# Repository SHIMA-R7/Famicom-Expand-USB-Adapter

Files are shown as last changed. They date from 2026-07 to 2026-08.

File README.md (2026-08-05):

# Famicom Expand USB Adapter

ファミリーベーシックキーボードとファミコン光線銃(ザッパー)を、USB HIDキーボード/マウスとしてPCで使えるようにするアダプター。

Arduino Nano(信号読み取り) + Raspberry Pi Pico(CircuitPython, USB HID出力)の2段構成。

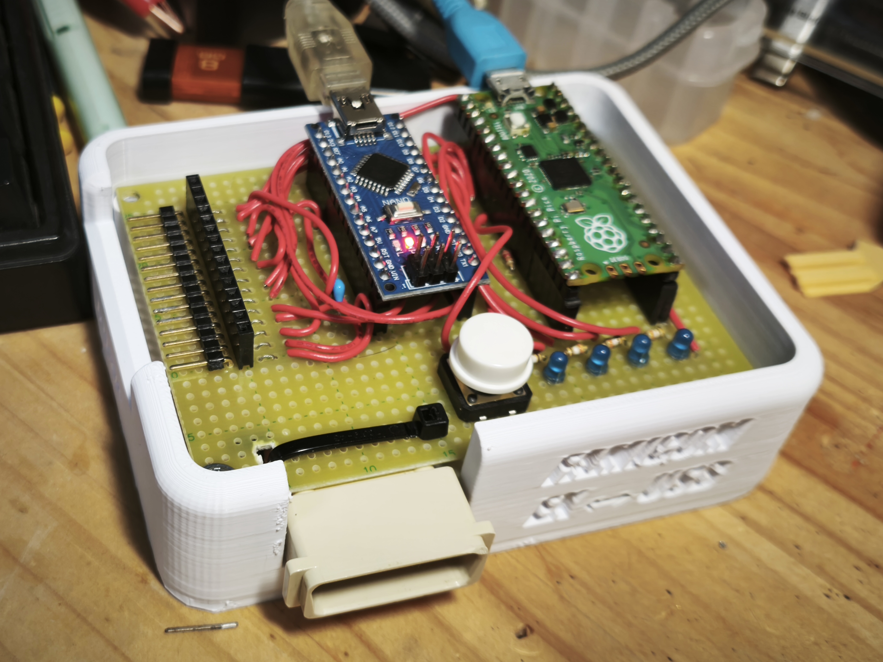
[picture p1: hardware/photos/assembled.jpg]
組み上がった実機


## 全体構成

```
[ファミコン拡張端子(15pin)] --- [Nano: 走査/読み取り] --UART(9600bps)--> [Pico: USB HID出力] --USB--> [PC]
```

- **Nano**: ファミリーベーシックキーボードのマトリクス走査、光線銃(トリガー/センサー)の読み取り。5Vネイティブロジックで駆動(キーボード内部の古いCMOS ICとレベル変換なしで直結するため)。
- **Pico**: CircuitPython動作。UART経由でNanoからのイベントを受信し、USB HIDキーボード/マウスとしてPCに送信。LEDインジケーター制御も担当。

詳しい配線・信号プロトコルは [docs/pinout.md](docs/pinout.md)、配線図は [docs/wiring-diagram.svg](docs/wiring-diagram.svg) を参照してください。

KiCadの正式な回路図(SFCコントローラーポート拡張込み)は [hardware/schematic/famicom-expand-usb-adapter.kicad_sch](hardware/schematic/famicom-expand-usb-adapter.kicad_sch)(閲覧だけなら[PDF](hardware/schematic/famicom-expand-usb-adapter.pdf)でもOK)、結線一覧表は [hardware/wiring/connection_list.xlsx](hardware/wiring/connection_list.xlsx) にあります。

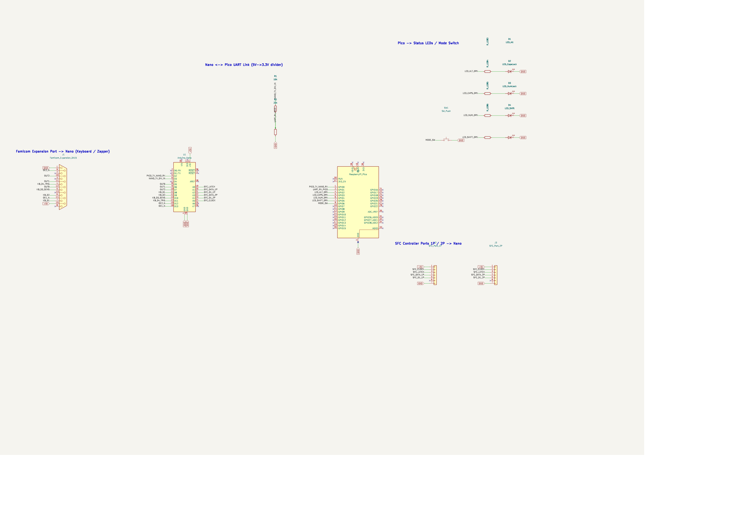
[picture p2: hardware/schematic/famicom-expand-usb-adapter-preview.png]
回路図プレビュー


## 実機での動作状況(2026-08-04時点)

- キーボードモード: 動作確認済み
- 光線銃(ザッパー)モード: 実機確認済み(トリガー→左クリック、センサー→右クリック)
- `_` / YENキーのHID Usage値は理論値のまま未実測(要検証)
- SFCコントローラー(標準パッド): **実機確認済み**。ボタン判定(アクティブLow)・並び(L=Q、R=Wなど)とも実装通りで反転不要だった
- SFCマウス: **完全に実機確認済み**(移動・左クリック・右クリック)。右ボタンは元のスイッチが導通不良だったためタクトスイッチに交換して解決。ファミコンベーシック用キーボードと同時使用しても問題なし

## ファームウェア

- [`firmware/nano/famicom_scanner.ino`](firmware/nano/famicom_scanner.ino) — Nano側。Arduino IDEで書き込み(ボード: Arduino Nano, ATmega328)。
- [`firmware/pico/code.py`](firmware/pico/code.py) — Pico側。CircuitPython + [adafruit_hid](https://github.com/adafruit/Adafruit_CircuitPython_HID) ライブラリが必要(`CIRCUITPY/lib/adafruit_hid` に配置)。Picoのファームウェア自体もCircuitPythonに書き換えておくこと(Arduino/arduino-picoコアでは不可、経緯は下記参照)。

### SFCコントローラー/マウス対応(パッド・マウスとも実機確認済み)

- 1P/2Pとも毎スキャンごとに32bit読み、**マウス固有のシグネチャ(生データのbyte1下位4bitが常に`1110`固定)で自動判定**(標準パッドは切替スイッチ不要、ホットスワップにも対応)。
  当初は「先頭バイトが0x00ならマウス」で判定していたが、**標準パッドもボタン全解放時は先頭バイトが同じ値になり誤判定する**ことが実機検証で判明したため、シグネチャ判定に変更した
- 信号は全ビットがアクティブLowで伝送されるため、マウスのbyte1/2/3は反転してから解釈する。**L/Rボタンはbyte1の上位2bit(bit7=Right、bit6=Left)** — 実機の分解調査でこの位置を確定した(資料によってはbit0/1側と記載されており誤りだった)
- 標準パッドのボタン(B/Y/Select/Start/Up/Down/Left/Right/A/X/L/R)は**キーボードキーとして出力**(1P: Z/A/RShift/Enter/矢印/X/S/Q/W、2P: テンキー、`code.py`の`KEYMAP_SFC1`/`KEYMAP_SFC2`で変更可能)
- マウスは移動量(dx/dy)・L/Rボタンを`Mouse.move()`/`press()`/`release()`に変換。SFC純正の分解能(感度0で50カウント/インチ相当)は今どきのUSBマウスよりかなり粗いため、`code.py`の`SFC_MOUSE_GAIN_DESKTOP`(既定12倍)で底上げしている。1回のHIDレポートは±127までなので、ゲイン後の移動量が超える分は複数回のmove()に分割して送信(単純にクランプすると速い動きが軒並み同じ最大値に潰れてカクつくため)。好みに応じて調整可
- **エミュレータで使うときは等倍に切り替える必要がある。** RetroArch等でSFCマウス対応ソフト(マリオペイント等)を動かす場合、エミュレータ側が期待しているのは「SFCマウス実機の生のカウント」なので、底上げ済みの値を渡すと二重に補正されてカーソルが吹っ飛び、まともに操作できない。**左右ボタン同時長押し(1秒)**で`SFC_MOUSE_GAIN_DESKTOP`(12倍)と`SFC_MOUSE_GAIN_NATIVE`(等倍)を切り替えられる。切替後はLEDで通知(等倍=1個点灯、12倍=4個点灯)。PC側で何が動いているかはPicoから知りようがないため自動判別はできず、手動切替としている。なお切替中の1秒間は左クリック押しっぱなしとして送られるので、描画されない場所で操作すること
- マウスの更新頻度はキーボード走査の行間の隙間を使って約10倍に上げてある(キーボードの走査速度自体は変えていない)。それでも体感するカクつきは、SFCマウス側センサーの応答限界による可能性が高い
- 1P/2Pどちらのマウスも同じUSBマウスカーソルを共有する(OS側の制約、2台同時使用時は移動が混ざる)
- ファミコン側(キーボード/ザッパー)とSFC側は配線・処理とも独立しているため、モード切替スイッチに関係なく**常時同時動作**。ファミリーベーシック用キーボード+SFCマウスの同時使用も確認済み
- Nano⇔Pico間のUARTは57600bpsに引き上げ(マウスは1回の更新で4バイト必要なため、9600bpsのままだと詰まる)
- ボタン/マウスボタンを押しっぱなしにしても、100ms間隔で状態を再送するようにしてある(Pico側の無通信ウォッチドッグが押しっぱなし中に誤って離してしまうのを防止)
- Nano側ループ末尾の待機を5ms→1msに短縮し、クリック/移動の応答性を上げた(キーボード走査自体は500us×18回≒9msかかるためこの短縮が主な効果)
- SFCボタンの読み取りにはキーボード側と同じデバウンス処理を追加済み。当初は未実装で、SELECT(右Shift)のチャタリングがWindowsの固定キー機能(Sticky Keys、Shift 5連打で起動)を誤爆させていた

パッド・マウス(移動/左クリック/右クリック)とも実機確認済み。右クリックは当初手元の個体のスイッチが導通不良だったが、タクトスイッチに交換して解決した。

## 光線銃テスト用ゲーム

[`tools/zapper-test/index.html`](tools/zapper-test/index.html) — ブラウザで開くだけで動く射撃ゲーム。ザッパーの実機動作確認用。

**光線銃には位置を検出する機能がない**(光センサーとトリガースイッチだけ)ため、実機のダックハントと同じ方式で命中判定している:

1. トリガーを引くと画面を**全黒**にする(この間に受光したら外光を拾っている = 不正として棄却。実機と同じ仕組み)
2. 画面上の的を**1つずつ順番に白い四角で点灯**させる
3. センサーが受光した**タイミング**から、どの的を狙っていたかを特定する

実機は1フレーム(16.6ms)ずつ点灯させるが、こちらはUSB HID経由のぶん遅延が乗るため**既定150ms**に伸ばしてある(画面上のスライダーで調整可)。この方式ならフレーム精度に依存しないので、実機と違って**LCDでも動作する**。

- 画面下のランプでトリガー/センサーの入力をリアルタイム表示。**ゲームを始めなくても配線チェックだけに使える**
- 撃った履歴と「走査何番目で受光したか」がログに残るので、チャタリングや取りこぼしの確認にも使える
- 命中しない場合は点灯時間を長くする、画面を明るくする、部屋を暗くする

Pico側がザッパーモード(GP6のスイッチ)になっていないと反応しないので注意。

## ハードウェア

### BOM(部品)

- Arduino Nano x1
- Raspberry Pi Pico x1
- タクトスイッチ x1(モード切替用)
- 抵抗 x6(UART電圧分圧用 10kΩ・22kΩ各1本 + LED電流制限用4本、値は手持ちに合わせて選定)
- LED x4(Shift / Alt / CapsLock / NumLockインジケーター)
- ピンソケット、ピンヘッダー(先曲がり)
- ビニール導線
- ユニバーサル基板: 秋月電子 [103230] 片面ガラスコンポジット・ユニバーサル基板 Bタイプ めっき仕上げ(95×72mm)日本製
- 3Dプリンターで自作した外装(ねじ止め)

外装STLは [`hardware/enclosure/Famicom_ExPand_to_USB_Flame.stl`](hardware/enclosure/Famicom_ExPand_to_USB_Flame.stl)。

### ファミコン拡張端子の取り出し

拡張端子コネクタ単体では基板から取り外せなかったため、ファミコン本体の基板ごと超音波カッターで切り抜いて使用。切り出した基板は結束バンドでユニバーサル基板/外装に固定している。

### SFCコントローラーポート拡張(配線済み、ファームウェア未実装)

スーファミ実機の1P/2Pコントローラーソケットをそのまま流用し、Nanoに追加接続。CLOCK・LATCH・+5V・GNDは1P/2Pで共通(実機と同じ配り方)、DATA線(4番ピン)とD1線(5番ピン、マウス/スーパースコープの拡張データ用)だけ1P/2Pそれぞれ別配線にする。6番ピン(IOBIT、マルチタップ検出用)は信号方向が未検証のため今回は未結線。

配線を楽にするため、SFC関連の信号は**全てアナログ側ピン(A0〜A5)に集約**している:

| 信号 | Nanoピン |
|---|---|
| CLOCK(1P/2P共通) | A5 |
| LATCH(1P/2P共通) | A0 |
| DATA(1P) | A1 |
| D1(1P) | A2 |
| DATA(2P) | A3 |
| D1(2P) | A4 |

当初は配線を減らすためA0・A1をファミコン拡張端子(DA15)の2番・3番ピンとも共用する案だったが、実機解析の結果**2番=AudioOUT、3番=IRQという実信号だと判明**したため共用を撤回、拡張端子側は物理的に切り離し済み。A0〜A5はSFC専用。これにより**ファミコンキーボード/ザッパーとSFCコントローラー/マウスは同時使用可能**(ザッパーとキーボードはDA15ソケットが1つしかないため引き続き排他)。

ファームウェア実装・実機確認とも完了(パッド/マウスとも動作確認済み、詳細は下記「ファームウェア」参照)。

## 既知の注意点

- キーボードと光線銃はDA15の4番・5番ピンを共用しているため、**同時接続は不可**(実機の前提通り)。トリガーを長押しするとキーボード側のマトリクス走査にも同じ物理ピンの変化が伝わり、擬似的なキーイベントが大量発生することを確認済み(キーボード未接続時は実害なし)。詳細は [docs/pinout.md](docs/pinout.md) 参照。
- DA15の2番・3番ピン(AudioOUT/IRQ)はNanoのA0・A1とは分離済み。SFCコントローラーはファミコンのキーボード/ザッパーと同時使用できる。
- Shift/Alt/Ctrlはすべてトグル方式(押すたびにON/OFF反転)。
- Nano→Pico方向のUARTのみ電圧分圧が必要(Pico→Nanoは直結でOK)。

## 開発の経緯・詰まったポイント(教訓)

1. ESP32-S3で検証を開始したが、3.3VロジックとキーボードのCMOS IC(4017/4019/4069)の相性が悪くチャタリング多発。Nanoの5Vネイティブロジックに変更して安定化。
2. キーボード走査プロトコルはnesdev/goroh氏の解析情報がベース。列選択後の待ち時間は寄生容量対策で300us→500usに増やして安定。
3. デバウンスは「行まるごと」ではなく「1キーごと(72キー個別)」でないと機能しなかった。
4. Arduino(arduino-picoコア)のKeyboardライブラリで「キー張り付き」バグに長時間ハマり、原因を特定できないまま**CircuitPython + adafruit_hidへ全面移行**して解決。
5. JIS配列とUS配列のHID Usage ID対応はズレるため、実測して1つずつ補正した。
6. Shift/Alt/Ctrlをトグル式にしたところ、ウォッチドッグ処理が誤ってShiftにも作用し、Windowsの「固定キー機能」を誤爆させた。ウォッチドッグの対象からShift/Alt/Ctrlのトグル状態を除外して解消。
7. Ctrl単体とShift+Alt同時トグルのLED表示が同じになり区別不能だった → 「Ctrl絡みは必ず点滅、Ctrlなしは必ず固定点灯」に統一。
8. モード切替スイッチのGPIOが一時「不調」と判明し別ピンに変更したが、後日の再検証では元のピンで問題なく動作。原因不明のため、また不調が出たら同様に疑うこと。

## 未確認・要検証事項

- `_`(0x87)、YEN(0x89)キーの実測補正
- ザッパーモードのLEDアニメーション速度(`ZAPPER_ANIM_STEP=0.15秒`)の調整
- SFCコントローラーポート: 実配線済み、Nano側の読み取りファームウェアはまだ未実装
- SFCコントローラーポート6番ピン(IOBIT)の信号方向・用途の実機検証

## 開発者より

- 今回の開発では主にClaudeを使っています。(要所要所の精査とか、雑用とかはGeminiやGPTも使ってる)途中で無料版のトークン制限にげんなりして課金しましたが、ClaudeCodeはいいですね、感動した。(周回遅れ)このレポジトリもClaudeがアップしてくれました。
- 検証とかはほぼほぼしてないです。コードが読めないので。基本的に体当たり検証です。
- 多分やろうと思えばPicoだけでもキーボードは使えます。ただ光線銃やその他周辺機器が必ずしもロジック電圧が合うとは限らないので、汎用性を重視してファミコンと同じ5VロジックのNanoをかましています。
- 問い合わせ先→[https://x.com/R_7_Rocket]

## 参考文献
[https://www.nesdev.org/wiki/Family_BASIC_Keyboard]
[https://nesmd.nomaki.jp/nes2.html]
ファミコンに関するすべてのハッカーに感謝を表します。

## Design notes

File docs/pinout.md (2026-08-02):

# Pinout / Protocol Reference

## Famicom expansion port (DA-15) pin assignment

Confirmed by measurement + WDIC / nesmd.nomaki.jp reference material.

| DA15 pin | Role | Nano pin |
|---|---|---|
| 1 | GND | GND |
| 2 | **AudioOUT** (confirmed 2026-08-02) | not connected |
| 3 | **IRQ** (confirmed 2026-08-02) | not connected |
| 4 | Keyboard D4 / **Zapper TRIGGER** | D11 |
| 5 | Keyboard D3 / **Zapper SENSOR** | D10 |
| 6 | Keyboard D2 | D9 |
| 7 | Keyboard D1 | D8 |
| 9 | /OE2 (found unused) | D12 (unused) |
| 10 | OUT2 | D7 |
| 11 | OUT1 | D6 |
| 12 | OUT0 | D5 |
| 14 | /OE1 (found unused) | D13 (unused) |
| 15 | +5V | Nano 5V |

**Note:** pins 4 and 5 are shared between the keyboard and the Zapper (the real
hardware assumes only one is ever connected at a time). Do not connect both
the keyboard and the Zapper simultaneously.

**Note:** pins 2 and 3 were initially assumed unused and briefly shared with
the SFC controller ports' LATCH and 1P DATA lines (Nano A0/A1) to simplify
wiring. Further investigation identified them as real Famicom signals
(AudioOUT / IRQ), so that sharing was reverted and the expansion-port side
was physically cut - A0/A1 are now dedicated solely to the SFC ports (full
SFC pin table in the main [README](../README.md)). Keyboard/Zapper and the
SFC controllers can be used at the same time; only keyboard vs Zapper stays
mutually exclusive, since both plug into the single J1 socket.

## Keyboard scan protocol

- 3-bit column select on OUT0/OUT1/OUT2 (equivalent to `$4016`): reset, then
  column 0, then column 1, scanning 9 rows.
- Reset: `0b101` (OUT0=1, OUT1=0, OUT2=1)
- Column 0 select: `0b100`
- Column 1 select: `0b110`
- Wait `delayMicroseconds(500)` after each column select before reading
  (parasitic capacitance; 300us was unstable).
- Data lines D1-D4 are read together. Not pressed = 1, pressed = 0 (inverted
  logic).

## Zapper

- Trigger: DA15 pin 4 (Nano D11)
- Sensor (light detect): DA15 pin 5 (Nano D10)
- Both are digital, active LOW on press / light detected.
- Assumes a Zapper with a NJL7502L + LM393 + NE555N-style output stage
  already driving DA15 pins 4/5.

## Pico GPIO assignment

| GPIO | Function |
|---|---|
| GP0 | UART0 TX -> Nano D2 (RX), direct connection |
| GP1 | UART0 RX <- Nano D3 (TX), **through voltage divider** |
| GP2 | Alt indicator LED |
| GP3 | CapsLock indicator LED (mirrors host lock state) |
| GP4 | NumLock indicator LED (mirrors host lock state) |
| GP5 | Shift indicator LED |
| GP6 | Mode switch (push button to GND) |

GP7 was tried for the mode switch earlier and turned out to be flaky; GP6 is
the pin currently in use (see main README for history).

## Nano <-> Pico UART level shift

Only the Nano(5V) -> Pico(3.3V) direction needs a divider. Pico -> Nano can
be wired directly.

```
Nano D3 (TX) --[10k]--+--[22k]-- GND
                       |
                   Pico GP1 (RX)

Nano D2 (RX) ------------------------ Pico GP0 (TX)
```

Divider output: 5V * 22/(10+22) ~= 3.44V (within Pico's tolerance).

## UART frame format (Nano -> Pico)

1 byte per event.

```
bit7: 1 = press, 0 = release
bit6-0: id (0-73)
```

- id 0-71: keyboard matrix (`row*8 + col*4 + bit`, 9 rows x 2 cols x 4 bits)
- id 72: Zapper trigger
- id 73: Zapper sensor

Baud rate: fixed at 9600bps.

## Key map (id -> key)

`row0`-`row8`, each row has `col0` (low nibble) / `col1` (high nibble),
bit0-3 = D1-D4.

```
row0: F8, RETURN, [, ]        | KANA(hankaku/zenkaku), RSHIFT, YEN, STOP(backspace)
row1: F7, @, :, ;             | _, /, -, ^
row2: F6, O, L, K             | ., ,, P, 0
row3: F5, I, U, J             | M, N, 9, 8
row4: F4, Y, G, H             | B, V, 7, 6
row5: F3, T, R, D             | F, C, 5, 4
row6: F2, W, S, A             | X, Z, E, 3
row7: F1, ESC, Q, CTR(Ctrl)   | LSHIFT, GRPH(Alt), 1, 2
row8: CLR_HOME, UP, RIGHT, LEFT | DOWN, SPACE, DEL, INS
```

### JIS layout symbol key corrections (measured on real hardware)

USB HID Usage IDs used directly (raw integers where `adafruit_hid.Keycode`
has no matching constant):

| Key | HID Usage |
|---|---|
| `[` | RIGHT_BRACKET (0x30) |
| `]` | BACKSLASH (0x31) |
| `@` | LEFT_BRACKET (0x2F) |
| `:` | QUOTE (0x34) |
| `;` | SEMICOLON (0x33, unchanged) |
| `_` | 0x87 (INTERNATIONAL1, raw value, **unverified on hardware**) |
| `-` | MINUS (0x2D) |
| `^` | EQUALS (0x2E) |
| YEN | 0x89 (INTERNATIONAL3, raw value, **unverified on hardware**) |
| KANA | 0x35 (hankaku/zenkaku) |

### Special behavior

- **Shift/Alt/Ctrl**: all **toggle** (each press flips on/off, not
  press-and-hold).
- **RETURN**: automatically releases Shift.
- **LED indicators** (keyboard mode):
  - Shift LED / Alt LED: reflect their own toggle state.
  - Ctrl alone: Shift and Alt LEDs both blink together.
  - Ctrl+Shift: Shift LED solid, Alt LED blinks.
  - Ctrl+Alt: Alt LED solid, Shift LED blinks.
  - Ctrl+Shift+Alt: Shift/Alt LEDs blink alternately.
  - CapsLock/NumLock LEDs: mirror the host PC's actual lock state
    (`kbd.led_on(Keyboard.LED_CAPS_LOCK)` etc).
- **Watchdog**: after 0.3s with no UART traffic, any held keyboard keys are
  force-released (Shift/Alt/Ctrl toggle state is intentionally excluded from
  this).

### Zapper mode

- Pressing the mode switch toggles keyboard mode <-> Zapper mode.
- In Zapper mode: id 72 (trigger) -> left mouse click, id 73 (sensor) ->
  right mouse click.
- Switching modes force-releases any held key/mouse button from the previous
  mode.
- LEDs while idle in Zapper mode: Alt -> Shift -> CapsLock -> NumLock chase
  animation (0.15s/step). While the trigger is held, all 4 blink together.

### Known interaction between keyboard and Zapper wiring

Because the trigger/sensor lines share the same physical pins as keyboard
D4/D3, holding the trigger down long enough also causes the keyboard matrix
scan to see the same signal change on every row for that bit, generating a
burst of spurious keyboard-matrix events (ids ending in the D4 bit position).
Confirmed on real hardware 2026-08-01: this happens for the trigger line
(long presses), not observed for the sensor line (likely filtered out by the
matrix scan's debounce, since sensor transitions tend to be shorter). This is
harmless as long as the keyboard is not connected at the same time.

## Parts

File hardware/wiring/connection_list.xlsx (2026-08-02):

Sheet: 部品表(BOM)
参照記号 | 部品名 | 仕様/値 | 数量 | 備考
U1 | Arduino Nano | ATmega328, 5V | 1 | 信号読み取り・SFC走査
U2 | Raspberry Pi Pico | CircuitPython | 1 | USB HID出力(キーボード/マウス)
J1 | ファミコン拡張端子(DA15) | 実機基板から切り出し | 1 | 超音波カッターで切り出し、結束バンド固定
J2 | SFCコントローラーポート(1P) | 7ピン、実機ソケット流用 | 1 | スーファミ実機フロントソケット
J3 | SFCコントローラーポート(2P) | 7ピン、実機ソケット流用 | 1 | スーファミ実機フロントソケット
R1 | 抵抗 | 10kΩ | 1 | UART分圧(Nano→Pico)
R2 | 抵抗 | 22kΩ | 1 | UART分圧(Nano→Pico)
R3 | 抵抗 | 値は手持ちに合わせて選定 | 1 | Alt LED電流制限
R4 | 抵抗 | 値は手持ちに合わせて選定 | 1 | CapsLock LED電流制限
R5 | 抵抗 | 値は手持ちに合わせて選定 | 1 | NumLock LED電流制限
R6 | 抵抗 | 値は手持ちに合わせて選定 | 1 | Shift LED電流制限
D1 | LED | 青(実機写真より) | 1 | Altインジケーター
D2 | LED | 青(実機写真より) | 1 | CapsLockインジケーター
D3 | LED | 青(実機写真より) | 1 | NumLockインジケーター
D4 | LED | 青(実機写真より) | 1 | Shiftインジケーター
SW1 | タクトスイッチ | モーメンタリ、GND側 | 1 | モード切替(キーボード⇔ザッパー/SFC)
- | ピンソケット/ピンヘッダー(先曲がり) | - | - | 基板⇔モジュール接続
- | ビニール導線 | - | - | 一般配線
- | ユニバーサル基板 | 秋月103230 片面ガラスコンポジット Bタイプ 95x72mm | 1
- | 3Dプリント外装 | STL: hardware/enclosure/Famicom_ExPand_to_USB_Flame.stl | 1 | ねじ止め

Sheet: 接続一覧
No. | 系統 | 接続元 | 接続先 | 信号名 | 備考
1 |  | J1 pin1 (GND) | U1 GND | GND | 共通GND
2 |  | J1 pin2 | 未結線 | AudioOUT | 実機解析でAudioOUTと判明。当初SFC_LATCHと共用する案があったが信号がぶつかるため切り離し済み
3 |  | J1 pin3 | 未結線 | IRQ | 実機解析でIRQと判明。当初SFC_DATA_1Pと共用する案があったが信号がぶつかるため切り離し済み
4 |  | J1 pin4 (KB D4/ザッパートリガー) | U1 D11 | KB_D4_TRIG | キーボード/ザッパー排他共用ピン、同時接続不可
5 |  | J1 pin5 (KB D3/ザッパーセンサー) | U1 D10 | KB_D3_SENS | 同上
6 |  | J1 pin6 (KB D2) | U1 D9 | KB_D2
7 |  | J1 pin7 (KB D1) | U1 D8 | KB_D1
8 |  | J1 pin9 (/OE2) | U1 D12 | OE2_N | 未使用信号、配線のみ
9 |  | J1 pin10 (OUT2) | U1 D7 | OUT2
10 |  | J1 pin11 (OUT1) | U1 D6 | OUT1
11 |  | J1 pin12 (OUT0) | U1 D5 | OUT0
12 |  | J1 pin14 (/OE1) | U1 D13 | OE1_N | 未使用信号、配線のみ
13 |  | J1 pin15 (+5V) | U1 5V | +5V | Nano側からアクセサリへ給電(出力方向)
14 |  | U1 D2 | U2 GP0 | UART_TX_PICO / RX_NANO | 直結(分圧不要)
15 |  | U1 D3 | R1 一端 | UART_TX_NANO | 分圧回路入力
16 |  | R1 他端 / R2 一端 | U2 GP1 | UART_RX_PICO | 分圧ノード、約3.44V
17 |  | R2 他端 | GND | GND
18 |  | U1 GND | U2 GND | GND | UART基準電位の共通化に必須
19 |  | U2 GP2 | R3 一端 | LED_ALT_DRV
20 |  | R3 他端 | D1 アノード | LED_ALT_DRV
21 |  | D1 カソード | GND | GND
22 |  | U2 GP3 | R4 一端 | LED_CAPS_DRV
23 |  | R4 他端 | D2 アノード | LED_CAPS_DRV
24 |  | D2 カソード | GND | GND
25 |  | U2 GP4 | R5 一端 | LED_NUM_DRV
26 |  | R5 他端 | D3 アノード | LED_NUM_DRV
27 |  | D3 カソード | GND | GND
28 |  | U2 GP5 | R6 一端 | LED_SHIFT_DRV
29 |  | R6 他端 | D4 アノード | LED_SHIFT_DRV
30 |  | D4 カソード | GND | GND
31 |  | U2 GP6 | SW1 一端 | MODE_SW | Pico内蔵プルアップ使用、外付け抵抗不要
32 |  | SW1 他端 | GND | GND
33 |  | J2 pin1 (+5V) | +5V(共通) | +5V | J1/J3と共通の給電ライン
34 |  | J2 pin2 (CLOCK) | U1 A5 | SFC_CLOCK | 1P/2P共通(J3と同一ネット)。全SFC信号をA0〜A5に集約
35 |  | J2 pin3 (LATCH) | U1 A0 | SFC_LATCH | 1P/2P共通(J3と同一ネット)。SFC専用(J1とは分離済み)
36 |  | J2 pin4 (DATA) | U1 A1 | SFC_DATA_1P | 標準ボタン用シリアルデータ。SFC専用(J1とは分離済み)
37 |  | J2 pin5 (D1) | U1 A2 | SFC_D1_1P | マウス/スーパースコープ用拡張データ
38 |  | J2 pin6 (IOBIT) | 未結線(保留) | SFC_IOBIT_1P | 信号方向未検証。マルチタップ対応時に配線
39 |  | J2 pin7 (GND) | GND(共通) | GND
40 |  | J3 pin1 (+5V) | +5V(共通) | +5V | J1/J2と共通の給電ライン
41 |  | J3 pin2 (CLOCK) | U1 A5 | SFC_CLOCK | J2と同一ネット(共通配線)
42 |  | J3 pin3 (LATCH) | U1 A0 | SFC_LATCH | J2と同一ネット(共通配線)
43 |  | J3 pin4 (DATA) | U1 A3 | SFC_DATA_2P | 標準ボタン用シリアルデータ
44 |  | J3 pin5 (D1) | U1 A4 | SFC_D1_2P | マウス/スーパースコープ用拡張データ
45 |  | J3 pin6 (IOBIT) | 未結線(保留) | SFC_IOBIT_2P | 信号方向未検証。マルチタップ対応時に配線
46 |  | J3 pin7 (GND) | GND(共通) | GND

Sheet: 共通ネット・空きピン
共通ネット一覧(複数箇所で同一信号)
ネット名 | 接続点 | 備考
+5V | U1 5V / J1 pin15 / J2 pin1 / J3 pin1 | Nano 5Vが全アクセサリの給電元(USB経由)
GND | U1 GND / U2 GND / J1 pin1 / J2 pin7 / J3 pin7 / R2他端 / D1〜D4カソード / SW1他端 | 全体で共通の基準電位
SFC_CLOCK | U1 A5 / J2 pin2 / J3 pin2 | 1P/2Pへ同時出力(実機と同じ配り方)
SFC_LATCH | U1 A0 / J2 pin3 / J3 pin3 | 1P/2Pへ同時出力(実機と同じ配り方)。SFC専用、ファミコン側とは分離済み
Nano 空きピン(2026-08-02時点)
ピン | 状態 | 備考
D0 | 予備 | ハードウェアSerial RX。デバッグ用シリアル(Serial.print)に温存推奨
D1 | 予備 | ハードウェアSerial TX。デバッグ用シリアル(Serial.print)に温存推奨
D4 | 予備 | SFC_CLOCKをA5に移設したため解放。SFC信号は全てA0〜A5に集約し配線を単純化
A6 | 予備(アナログ専用) | デジタル入出力不可、アナログ読み取りのみ
A7 | 予備(アナログ専用) | デジタル入出力不可、アナログ読み取りのみ

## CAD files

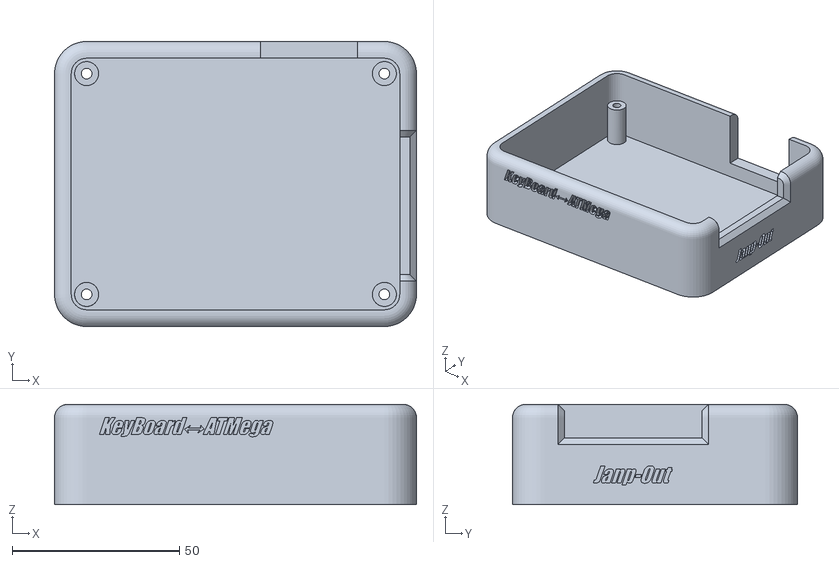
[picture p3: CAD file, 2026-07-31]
hardware/enclosure/Famicom_ExPand_to_USB_Flame.stl
108.2 x 85.2 x 30.0

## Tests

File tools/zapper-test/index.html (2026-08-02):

# Zapper Test Range

光線銃 / ダックハント方式の走査で命中判定

Score 0

Hit 0

Miss 0

Shots 0

Time 45

## Ready

ファミコン実機と同じダックハント方式で判定します。光線銃に位置を測る機能はないため、 撃った瞬間に画面を走査して「どの的を狙っていたか」を光で判別します。

1. トリガーを引くと画面が全黒になる(不正防止のチェック)
2. 的が1つずつ順番に白く光る
3. センサーが光を検知した瞬間の的が命中

Picoをザッパーモード(GP6のスイッチ)にしてから開始してください。 画面の明るさは上げ、部屋は暗めにすると検知しやすくなります。

Start

点灯時間 150ms 黒画面 150ms

Trigger — 左クリック id 72 / DA15 4番ピン

Sensor — 右クリック id 73 / DA15 5番ピン

ランプはゲーム外でも常時反応するので、配線チェックだけにも使えます。 命中しない場合は「点灯時間」を長くすると検知しやすくなります(USB HID経由のぶん実機より遅延があるため、 実機の1フレーム=16.6msでは間に合いません)。黒画面中にセンサーが反応する場合は、 周囲の照明を拾っているかzapper_mode以外の信号が来ています。

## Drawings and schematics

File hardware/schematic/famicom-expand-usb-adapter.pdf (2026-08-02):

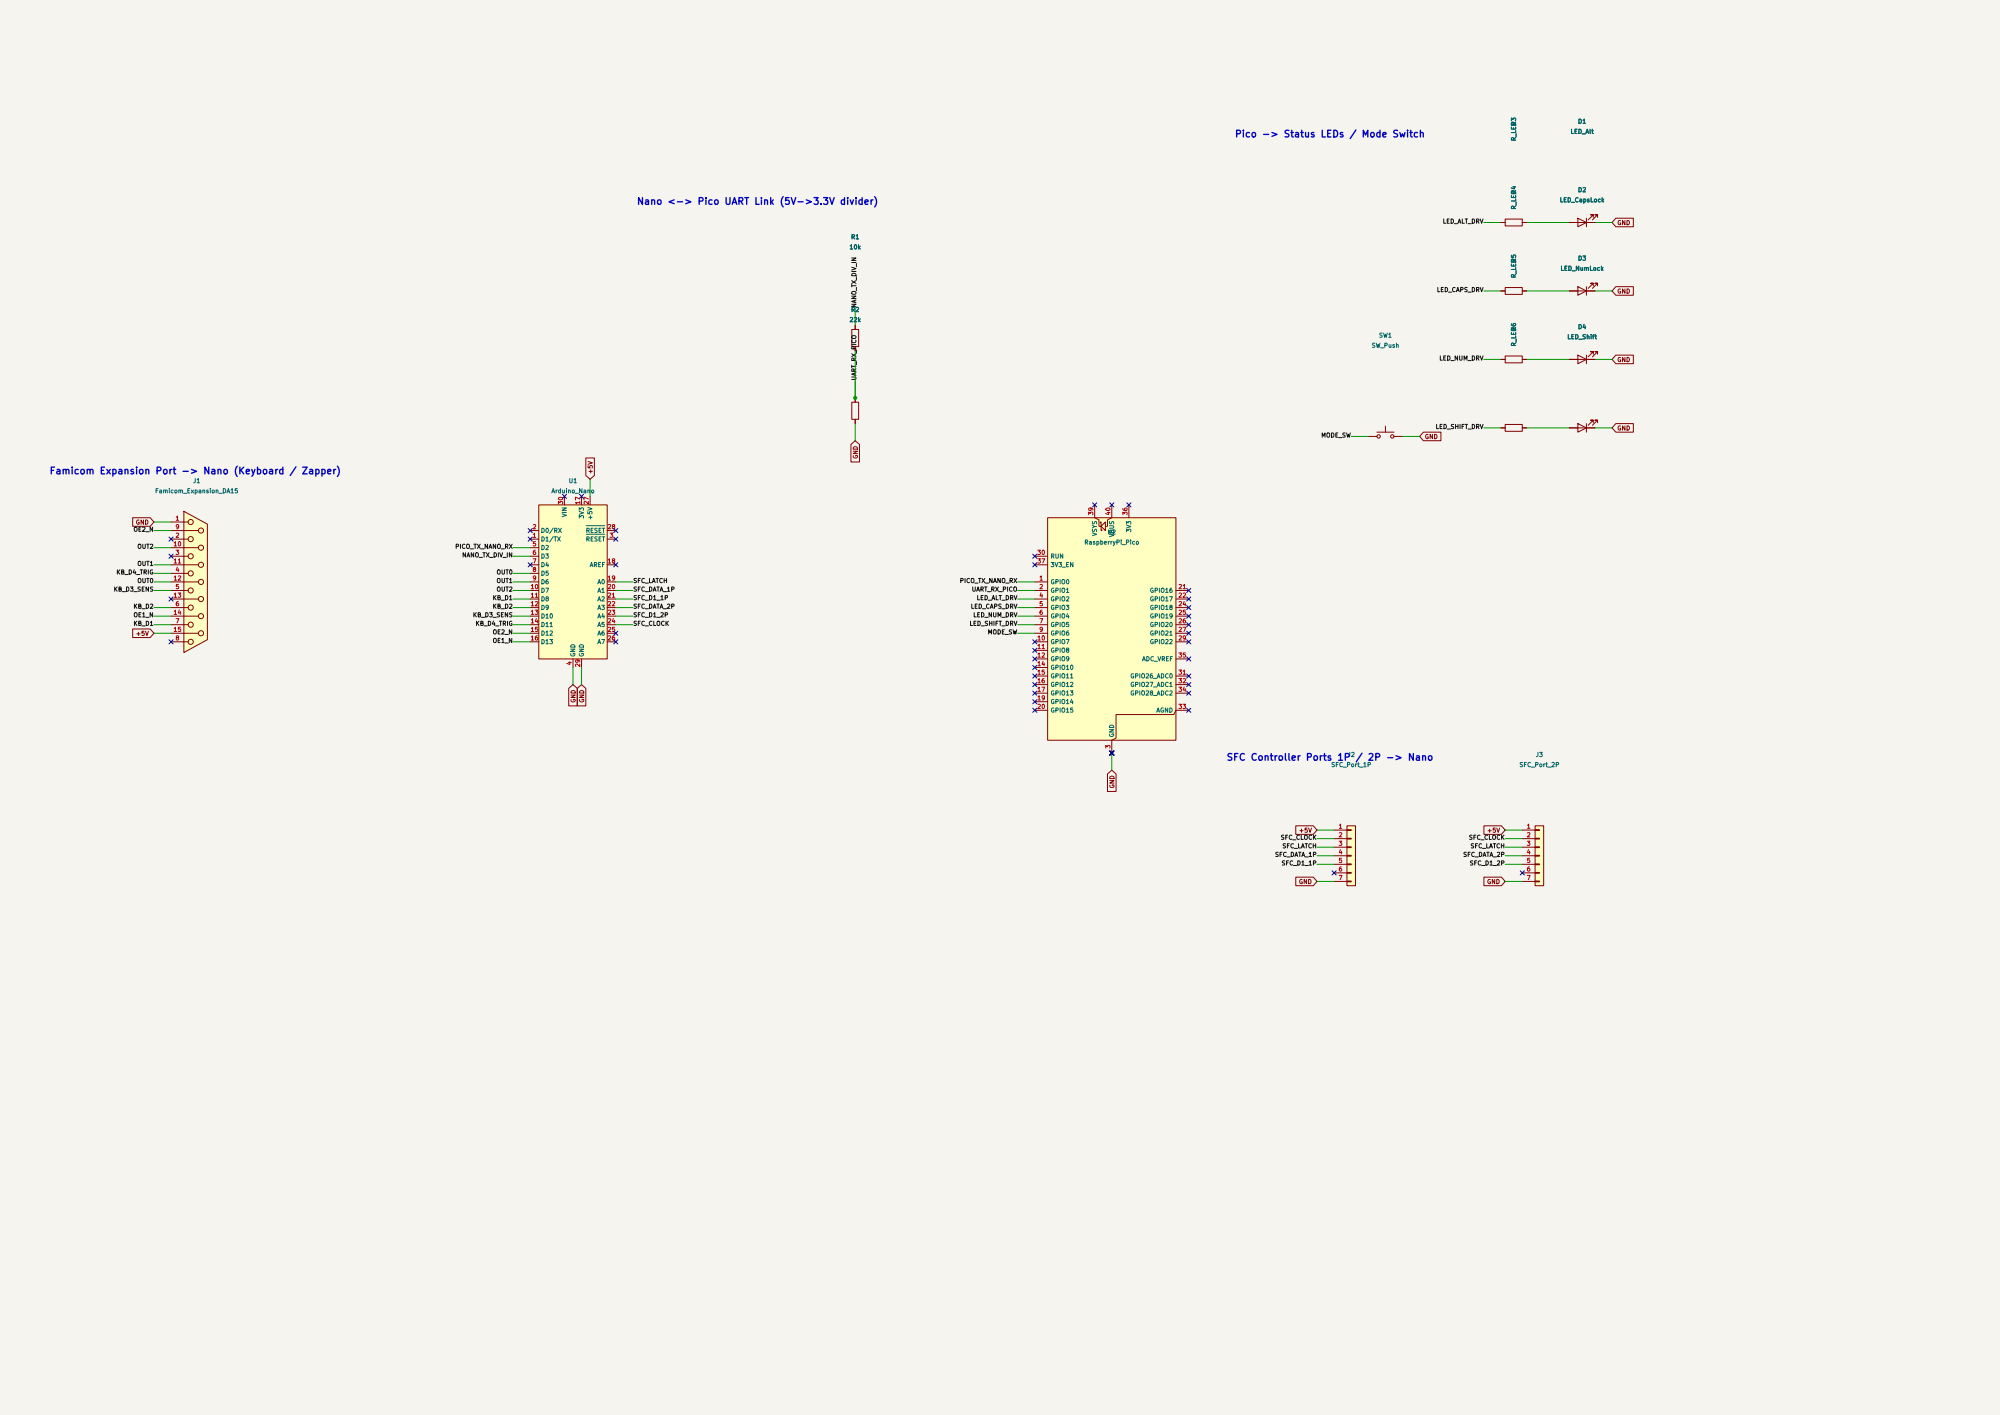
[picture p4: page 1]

Pico -> Status LEDs / Mode Switch

Nano <-> Pico UART Link (5V->3.3V divider)

Famicom Expansion Port -> Nano (Keyboard / Zapper)

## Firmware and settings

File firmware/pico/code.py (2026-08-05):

import time
import board
import busio
import digitalio
import usb_hid
from adafruit_hid.keyboard import Keyboard
from adafruit_hid.keycode import Keycode
from adafruit_hid.mouse import Mouse

uart = busio.UART(board.GP0, board.GP1, baudrate=57600, timeout=0.01)
kbd = Keyboard(usb_hid.devices)
mouse = Mouse(usb_hid.devices)

mode_switch = digitalio.DigitalInOut(board.GP6)
mode_switch.direction = digitalio.Direction.INPUT
mode_switch.pull = digitalio.Pull.UP
zapper_mode = False
switch_last_state = True

shift_led = digitalio.DigitalInOut(board.GP5)
shift_led.direction = digitalio.Direction.OUTPUT
alt_led = digitalio.DigitalInOut(board.GP2)
alt_led.direction = digitalio.Direction.OUTPUT
capslock_led = digitalio.DigitalInOut(board.GP3)
capslock_led.direction = digitalio.Direction.OUTPUT
numlock_led = digitalio.DigitalInOut(board.GP4)
numlock_led.direction = digitalio.Direction.OUTPUT

HANZEN_ZENKAKU = 0x35

KEYMAP = [
    Keycode.F8, Keycode.ENTER, Keycode.RIGHT_BRACKET, Keycode.BACKSLASH,
    HANZEN_ZENKAKU, Keycode.RIGHT_SHIFT, 0x89, Keycode.BACKSPACE,
    Keycode.F7, Keycode.LEFT_BRACKET, Keycode.QUOTE, Keycode.SEMICOLON,
    0x87, Keycode.FORWARD_SLASH, Keycode.MINUS, Keycode.EQUALS,
    Keycode.F6, Keycode.O, Keycode.L, Keycode.K,
    Keycode.PERIOD, Keycode.COMMA, Keycode.P, Keycode.ZERO,
    Keycode.F5, Keycode.I, Keycode.U, Keycode.J,
    Keycode.M, Keycode.N, Keycode.NINE, Keycode.EIGHT,
    Keycode.F4, Keycode.Y, Keycode.G, Keycode.H,
    Keycode.B, Keycode.V, Keycode.SEVEN, Keycode.SIX,
    Keycode.F3, Keycode.T, Keycode.R, Keycode.D,
    Keycode.F, Keycode.C, Keycode.FIVE, Keycode.FOUR,
    Keycode.F2, Keycode.W, Keycode.S, Keycode.A,
    Keycode.X, Keycode.Z, Keycode.E, Keycode.THREE,
    Keycode.F1, Keycode.ESCAPE, Keycode.Q, Keycode.LEFT_CONTROL,
    Keycode.LEFT_SHIFT, Keycode.LEFT_ALT, Keycode.ONE, Keycode.TWO,
    Keycode.HOME, Keycode.UP_ARROW, Keycode.RIGHT_ARROW, Keycode.LEFT_ARROW,
    Keycode.DOWN_ARROW, Keycode.SPACE, Keycode.BACKSPACE, Keycode.INSERT,
]

SHIFT_CODES = (Keycode.LEFT_SHIFT, Keycode.RIGHT_SHIFT)
ALT_CODES = (Keycode.LEFT_ALT, Keycode.RIGHT_ALT)
CTRL_CODES = (Keycode.LEFT_CONTROL, Keycode.RIGHT_CONTROL)

# SFCコントローラー: id 74-85(1P)/86-97(2P)、並びはB,Y,Select,Start,Up,Down,Left,Right,A,X,L,R
# 押しっぱなし方式(トグルではない)。好みに応じて自由に差し替え可。
SFC1_BUTTON_BASE = 74
SFC2_BUTTON_BASE = 86
SFC1_MOUSE_ID = 98
SFC2_MOUSE_ID = 99
# SFCマウス純正の分解能(感度0で50カウント/インチ程度)は今どきのUSBマウスよりかなり
# 粗いので、そのまま送ると動きが鈍く感じる。ここで倍率をかけて感度を底上げする。
#
# ただしエミュレータで本物のSFCソフト(マリオペイント等)を動かすときは話が逆になる。
# エミュレータ側は「SFCマウス実機のカウント」を期待しているので、底上げ済みの値を
# 渡すと二重に補正されてカーソルが吹っ飛び、まともに描けない。その用途では等倍
# (=実機と同じ生のカウント)に戻す必要がある。
# PC側で何が動いているかはPicoからは分からないため、左右ボタン同時長押しで手動切替。
SFC_MOUSE_GAIN_DESKTOP = 12  # PCの普通のマウスとして使うとき
SFC_MOUSE_GAIN_NATIVE = 1    # エミュレータでSFCマウスとして使うとき(実機同等)
SFC_MOUSE_GAIN_HOLD = 1.0    # 切り替えに必要な同時押し時間(秒)
SFC_GAIN_FEEDBACK = 1.2      # 切り替え後にLEDで知らせる時間(秒)

KEYMAP_SFC1 = [
    Keycode.Z, Keycode.A, Keycode.RIGHT_SHIFT, Keycode.ENTER,
    Keycode.UP_ARROW, Keycode.DOWN_ARROW, Keycode.LEFT_ARROW, Keycode.RIGHT_ARROW,
    Keycode.X, Keycode.S, Keycode.Q, Keycode.W,
]
KEYMAP_SFC2 = [
    Keycode.KEYPAD_ONE, Keycode.KEYPAD_SEVEN, Keycode.KEYPAD_ZERO, Keycode.KEYPAD_ENTER,
    Keycode.KEYPAD_EIGHT, Keycode.KEYPAD_TWO, Keycode.KEYPAD_FOUR, Keycode.KEYPAD_SIX,
    Keycode.KEYPAD_THREE, Keycode.KEYPAD_NINE, Keycode.KEYPAD_MINUS, Keycode.KEYPAD_PLUS,
]

last_packet_time = time.monotonic()
WATCHDOG_TIMEOUT = 0.3
shift_active = False
alt_active = False
ctrl_active = False
pressed_keys = set()
trigger_held = False

# SFCコントローラー/マウスはキーボードモード・ザッパーモードどちらでも常時動作する
# (ファミコン側とSFC側は配線・信号とも独立しているため同時利用可能)
sfc_pressed_keys = set()
sfc1_mouse_buttons = 0
sfc2_mouse_buttons = 0
sfc_last_packet_time = time.monotonic()

sfc_mouse_gain = SFC_MOUSE_GAIN_DESKTOP
sfc_both_since = None       # 左右同時押しが始まった時刻(Noneなら同時押し中でない)
sfc_gain_toggled = False    # この同時押しで既に切り替え済みか(1回の長押しで1回だけ)
gain_feedback_until = 0.0   # この時刻まではLEDに現在の倍率を表示する

BLINK_STEP_DURATION = 0.25
blink_step_start = time.monotonic()
blink_phase = 0

# ==== ザッパーモード用アニメーション(alt→shift→capslock→numlock) ====
ZAPPER_ANIM_STEP = 0.15
zapper_anim_start = time.monotonic()
zapper_anim_index = 0
ZAPPER_ANIM_LEDS = [alt_led, shift_led, capslock_led, numlock_led]


def release_shift():
    global shift_active
    if shift_active:
        shift_active = False
        kbd.release(Keycode.LEFT_SHIFT)


def release_all_modifiers_and_keys():
    global shift_active, alt_active, ctrl_active
    for c in list(pressed_keys):
        kbd.release(c)
    pressed_keys.clear()
    if shift_active:
        kbd.release(Keycode.LEFT_SHIFT)
        shift_active = False
    if alt_active:
        kbd.release(Keycode.LEFT_ALT)
        alt_active = False
    if ctrl_active:
        kbd.release(Keycode.LEFT_CONTROL)
        ctrl_active = False


def update_leds_keyboard_mode():
    global blink_step_start, blink_phase

    now = time.monotonic()
    if now - blink_step_start >= BLINK_STEP_DURATION:
        blink_phase = 1 - blink_phase
        blink_step_start = now
    blink_on = (blink_phase == 0)

    if not ctrl_active:
        shift_led.value = shift_active
        alt_led.value = alt_active
    elif shift_active and alt_active:
        shift_led.value = blink_on
        alt_led.value = not blink_on
    elif shift_active and not alt_active:
        shift_led.value = True
        alt_led.value = blink_on
    elif alt_active and not shift_active:
        shift_led.value = blink_on
        alt_led.value = True
    else:
        shift_led.value = blink_on
        alt_led.value = blink_on

    capslock_led.value = kbd.led_on(Keyboard.LED_CAPS_LOCK)
    numlock_led.value = kbd.led_on(Keyboard.LED_NUM_LOCK)


def update_leds_zapper_mode():
    global zapper_anim_start, zapper_anim_index

    if trigger_held:
        # トリガー中は全部同時点滅
        now = time.monotonic()
        if now - zapper_anim_start >= ZAPPER_ANIM_STEP:
            zapper_anim_index = 1 - zapper_anim_index
            zapper_anim_start = now
        on = (zapper_anim_index == 0)
        for led in ZAPPER_ANIM_LEDS:
            led.value = on
    else:
        # 待機中はalt→shift→capslock→numlockの順に流れる
        now = time.monotonic()
        if now - zapper_anim_start >= ZAPPER_ANIM_STEP:
            zapper_anim_index = (zapper_anim_index + 1) % len(ZAPPER_ANIM_LEDS)
            zapper_anim_start = now
        for i, led in enumerate(ZAPPER_ANIM_LEDS):
            led.value = (i == zapper_anim_index)


def update_leds_gain_feedback():
    """マウス倍率を切り替えた直後、どちらになったかをLEDで知らせる。

    等倍(エミュ用)は1個だけ点灯、12倍(デスクトップ用)は4個全点灯。
    キーボード/ザッパー用のLED更新より優先して呼ぶ。
    """
    native = (sfc_mouse_gain == SFC_MOUSE_GAIN_NATIVE)
    for i, led in enumerate(ZAPPER_ANIM_LEDS):
        led.value = True if not native else (i == 0)


print("keyboard/zapper bridge start")

while True:
    try:
        sw = mode_switch.value
        if sw != switch_last_state:
            if sw == False:
                zapper_mode = not zapper_mode
                if zapper_mode:
                    release_all_modifiers_and_keys()
                else:
                    mouse.release_all()
                    trigger_held = False
                zapper_anim_index = 0
                zapper_anim_start = time.monotonic()
            switch_last_state = sw

        data = uart.read(1)
        if data:
            packet = data[0]
            pressed = bool(packet & 0x80)
            key_id = packet & 0x7F
            last_packet_time = time.monotonic()
            sfc_last_packet_time = last_packet_time

            if key_id == 72:  # トリガー
                if zapper_mode:
                    trigger_held = pressed
                    if pressed:
                        mouse.press(Mouse.LEFT_BUTTON)
                    else:
                        mouse.release(Mouse.LEFT_BUTTON)

            elif key_id == 73:  # センサー
                if zapper_mode:
                    if pressed:
                        mouse.press(Mouse.RIGHT_BUTTON)
                    else:
                        mouse.release(Mouse.RIGHT_BUTTON)

            elif SFC1_BUTTON_BASE <= key_id < SFC1_BUTTON_BASE + 12:
                # キーボード/ザッパーのモードに関係なく常時有効
                code = KEYMAP_SFC1[key_id - SFC1_BUTTON_BASE]
                if pressed:
                    kbd.press(code)
                    sfc_pressed_keys.add(code)
                else:
                    kbd.release(code)
                    sfc_pressed_keys.discard(code)

            elif SFC2_BUTTON_BASE <= key_id < SFC2_BUTTON_BASE + 12:
                code = KEYMAP_SFC2[key_id - SFC2_BUTTON_BASE]
                if pressed:
                    kbd.press(code)
                    sfc_pressed_keys.add(code)
                else:
                    kbd.release(code)
                    sfc_pressed_keys.discard(code)

            elif key_id in (SFC1_MOUSE_ID, SFC2_MOUSE_ID):
                # ヘッダーに続けてbuttons/dx/dyの3バイトが来る
                payload = uart.read(3)
                if payload and len(payload) == 3:
                    buttons = payload[0]
                    dx = payload[1] - 256 if payload[1] > 127 else payload[1]
                    dy = payload[2] - 256 if payload[2] > 127 else payload[2]
                    # 1回のHIDレポートは±127までしか送れないので、ゲインをかけた後の
                    # 総移動量が127を超える分は複数回に分けて送る(単純にクランプすると
                    # 速い動きが軒並み同じ最大値に潰れてカクついて見えるため)
                    total_dx = dx * sfc_mouse_gain
                    total_dy = dy * sfc_mouse_gain
                    while total_dx != 0 or total_dy != 0:
                        step_dx = max(-127, min(127, total_dx))
                        step_dy = max(-127, min(127, total_dy))
                        mouse.move(step_dx, step_dy, 0)
                        total_dx -= step_dx
                        total_dy -= step_dy
                    if key_id == SFC1_MOUSE_ID:
                        changed = buttons ^ sfc1_mouse_buttons
                        sfc1_mouse_buttons = buttons
                    else:
                        changed = buttons ^ sfc2_mouse_buttons
                        sfc2_mouse_buttons = buttons
                    if changed & 0x01:
                        (mouse.press if buttons & 0x01 else mouse.release)(Mouse.LEFT_BUTTON)
                    if changed & 0x02:
                        (mouse.press if buttons & 0x02 else mouse.release)(Mouse.RIGHT_BUTTON)

                    # 左右同時長押しでデスクトップ用(12倍)とエミュ用(等倍)を切り替える。
                    # PC側の状況はPicoから見えないので、切り替えは手動でしかできない。
                    if buttons & 0x03 == 0x03:
                        if sfc_both_since is None:
                            sfc_both_since = time.monotonic()
                        elif (not sfc_gain_toggled
                              and time.monotonic() - sfc_both_since >= SFC_MOUSE_GAIN_HOLD):
                            sfc_mouse_gain = (SFC_MOUSE_GAIN_NATIVE
                                              if sfc_mouse_gain == SFC_MOUSE_GAIN_DESKTOP
                                              else SFC_MOUSE_GAIN_DESKTOP)
                            sfc_gain_toggled = True
                            gain_feedback_until = time.monotonic() + SFC_GAIN_FEEDBACK
                            print("SFC mouse gain ->", sfc_mouse_gain)
                    else:
                        sfc_both_since = None
                        sfc_gain_toggled = False

            elif not zapper_mode and key_id < len(KEYMAP):
                code = KEYMAP[key_id]
                if code is not None:
                    if code in SHIFT_CODES:
                        if pressed:
                            shift_active = not shift_active
                            if shift_active:
                                kbd.press(Keycode.LEFT_SHIFT)
                            else:
                                kbd.release(Keycode.LEFT_SHIFT)
                    elif code in ALT_CODES:
                        if pressed:
                            alt_active = not alt_active
                            if alt_active:
                                kbd.press(Keycode.LEFT_ALT)
                            else:
                                kbd.release(Keycode.LEFT_ALT)
                    elif code in CTRL_CODES:
                        if pressed:
                            ctrl_active = not ctrl_active
                            if ctrl_active:
                                kbd.press(Keycode.LEFT_CONTROL)
                            else:
                                kbd.release(Keycode.LEFT_CONTROL)
                    else:
                        if pressed:
                            kbd.press(code)
                            pressed_keys.add(code)
                            if code == Keycode.ENTER:
                                release_shift()
                        else:
                            kbd.release(code)
                            pressed_keys.discard(code)

        if not zapper_mode and time.monotonic() - last_packet_time > WATCHDOG_TIMEOUT and pressed_keys:
            for c in list(pressed_keys):
                kbd.release(c)
            pressed_keys.clear()
            last_packet_time = time.monotonic()

        if time.monotonic() - sfc_last_packet_time > WATCHDOG_TIMEOUT and (sfc_pressed_keys or sfc1_mouse_buttons or sfc2_mouse_buttons):
            for c in list(sfc_pressed_keys):
                kbd.release(c)
            sfc_pressed_keys.clear()
            if sfc1_mouse_buttons or sfc2_mouse_buttons:
                mouse.release_all()
                sfc1_mouse_buttons = 0
                sfc2_mouse_buttons = 0
            sfc_last_packet_time = time.monotonic()

        if time.monotonic() < gain_feedback_until:
            update_leds_gain_feedback()
        elif zapper_mode:
            update_leds_zapper_mode()
        else:
            update_leds_keyboard_mode()

    except Exception as e:
        print("ERROR:", e)
        try:
            release_all_modifiers_and_keys()
            mouse.release_all()
            for c in list(sfc_pressed_keys):
                kbd.release(c)
            sfc_pressed_keys.clear()
            sfc1_mouse_buttons = 0
            sfc2_mouse_buttons = 0
        except Exception:
            pass
        last_packet_time = time.monotonic()
        sfc_last_packet_time = time.monotonic()

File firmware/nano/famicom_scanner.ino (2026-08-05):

#include <SoftwareSerial.h>

const int OUT0 = 5;
const int OUT1 = 6;
const int OUT2 = 7;
const int D1 = 8;
const int D2 = 9;
const int D3 = 10;
const int D4 = 11;

const int ZAPPER_TRIGGER = 11; // DA15 4番ピン ※D4と物理配線共用(排他利用前提)
const int ZAPPER_SENSOR  = 10; // DA15 5番ピン ※D3と物理配線共用(排他利用前提)

// SFCコントローラーポート(1P/2P)。CLOCK/LATCHは共通、DATAのみポートごと。
const int SFC_CLOCK    = A5;
const int SFC_LATCH    = A0;
const int SFC_DATA_1P  = A1;
const int SFC_DATA_2P  = A3;
// A2(1P D1)・A4(2P D1)は標準パッド/マウスとも未使用のため未配線

SoftwareSerial toPico(2, 3); // RX=D2, TX=D3(分圧経由でPico GP1へ)

bool stableState[9][2][4];
bool candidateState[9][2][4];
uint8_t candidateCount[9][2][4];
bool firstScan = true;
const uint8_t DEBOUNCE_THRESHOLD = 2;

bool lastTrigger = HIGH;
bool lastSensor = HIGH;

// SFC 1P/2Pの状態(id 74〜85=1Pボタン、86〜97=2Pボタン、98=1Pマウス、99=2Pマウス)
const uint8_t SFC1_BUTTON_BASE = 74;
const uint8_t SFC2_BUTTON_BASE = 86;
const uint8_t SFC1_MOUSE_ID = 98;
const uint8_t SFC2_MOUSE_ID = 99;
// ボタン並び(クロック順): B, Y, Select, Start, Up, Down, Left, Right, A, X, L, R
bool sfc1PadButtons[12] = {false};
bool sfc2PadButtons[12] = {false};
// SFCボタンのデバウンス用(キーボード側と同じ考え方)。SELECT(右Shift)がチャタリングで
// 連打扱いされ、Windowsの固定キー機能(Sticky Keys)を誤爆させたため追加した。
bool sfc1PadCandidate[12] = {false};
uint8_t sfc1PadCandidateCount[12] = {0};
bool sfc2PadCandidate[12] = {false};
uint8_t sfc2PadCandidateCount[12] = {0};
bool sfc1IsMouse = false;
bool sfc2IsMouse = false;
uint8_t sfc1MouseButtons = 0;
uint8_t sfc2MouseButtons = 0;

void writeOut(uint8_t v) {
  digitalWrite(OUT0, v & 1);
  digitalWrite(OUT1, (v >> 1) & 1);
  digitalWrite(OUT2, (v >> 2) & 1);
}

uint8_t readNibble() {
  uint8_t b = 0;
  b |= digitalRead(D1) << 0;
  b |= digitalRead(D2) << 1;
  b |= digitalRead(D3) << 2;
  b |= digitalRead(D4) << 3;
  return b;
}

void sendEvent(int row, int col, int bit, bool pressed) {
  uint8_t id = row * 8 + col * 4 + bit;
  uint8_t packet = (pressed ? 0x80 : 0x00) | id;
  toPico.write(packet);
}

void processBit(int row, int col, int bit, bool rawOn) {
  if (firstScan) {
    stableState[row][col][bit] = rawOn;
    candidateState[row][col][bit] = rawOn;
    candidateCount[row][col][bit] = DEBOUNCE_THRESHOLD;
    return;
  }
  if (rawOn == candidateState[row][col][bit]) {
    if (candidateCount[row][col][bit] < 255) candidateCount[row][col][bit]++;
  } else {
    candidateState[row][col][bit] = rawOn;
    candidateCount[row][col][bit] = 1;
  }
  if (candidateCount[row][col][bit] >= DEBOUNCE_THRESHOLD &&
      stableState[row][col][bit] != rawOn) {
    sendEvent(row, col, bit, !rawOn);
    stableState[row][col][bit] = rawOn;
  }
}

void scanKeyboard() {
  writeOut(0b101);
  delayMicroseconds(500);
  for (int row = 0; row < 9; row++) {
    writeOut(0b100);
    delayMicroseconds(500);
    uint8_t col0 = readNibble();
    writeOut(0b110);
    delayMicroseconds(500);
    uint8_t col1 = readNibble();
    for (int bit = 0; bit < 4; bit++) {
      processBit(row, 0, bit, (col0 >> bit) & 1);
      processBit(row, 1, bit, (col1 >> bit) & 1);
    }
    // キーボード走査は1行ごとに待ち時間があるだけの遅い処理なので、その合間に
    // SFC(マウス)を読んでおくと、キーボードの走査速度を落とさずにマウスの
    // 更新頻度だけ約10倍に上げられる(カクつき対策)
    scanSFC();
  }
  firstScan = false;
}

void scanZapper() {
  bool trig = digitalRead(ZAPPER_TRIGGER);
  if (trig != lastTrigger) {
    toPico.write((trig == LOW ? 0x80 : 0x00) | 72); // id=72 トリガー
    lastTrigger = trig;
  }
  bool sens = digitalRead(ZAPPER_SENSOR);
  if (sens != lastSensor) {
    toPico.write((sens == LOW ? 0x80 : 0x00) | 73); // id=73 センサー
    lastSensor = sens;
  }
}

void sendSFCPadEvent(uint8_t baseId, int index, bool pressed) {
  toPico.write((pressed ? 0x80 : 0x00) | (baseId + index));
}

// 32bit丸ごと読んだ後、標準パッドかマウスかを判定して処理する。
// ホットスワップにも対応(毎スキャンごとに再判定)。
//
// 実機解析で確定した仕様(2026-08-02):
// - 信号線は全ビットがアクティブLowで伝送される(論理値の反転がそのまま生値になる)
// - マウスは生のbyte1下位4bitが常に0b1110固定(論理シグネチャ0001の反転)。
//   これはパッドの「先頭バイトが0x00かどうか」では判定できない
//   (パッドもボタン全解放時は先頭バイトが生0xFFになり、マウスの生0xFFと衝突するため)
// - L/Rボタンは(反転後の)byte1の上位2bit: bit7=Right、bit6=Left
// force=trueの時は「変化なし」でも現在押されているボタンを再送する(Pico側の
// ウォッチドッグが、押しっぱなし中に無通信と誤認して勝手に離してしまうのを防ぐため)
void processSFCPort(uint32_t report, uint8_t buttonBaseId, uint8_t mouseId,
                     bool &isMouse, bool padButtons[12], uint8_t &mouseButtons, bool force,
                     bool padCandidate[12], uint8_t padCandidateCount[12]) {
  uint8_t rawByte1 = (report >> 16) & 0xFF;
  bool mouseReport = (rawByte1 & 0x0F) == 0x0E; // マウス固有シグネチャ(実測確定)
  if (mouseReport) {
    // マウスレポート
    if (!isMouse) {
      // パッドモードから切り替わった瞬間、押しっぱなしのボタンを強制解放
      for (int i = 0; i < 12; i++) {
        if (padButtons[i]) {
          sendSFCPadEvent(buttonBaseId, i, false);
          padButtons[i] = false;
        }
      }
      isMouse = true;
    }
    uint8_t byte1 = ~rawByte1 & 0xFF;               // bit7=Right bit6=Left bit5-4=感度 bit3-0=signature(0001)
    uint8_t byte2 = ~((report >> 8) & 0xFF) & 0xFF; // Y方向(bit7=符号, bit6-0=移動量)
    uint8_t byte3 = ~report & 0xFF;                 // X方向(bit7=符号, bit6-0=移動量)
    uint8_t newButtons = 0;
    if (byte1 & 0x40) newButtons |= 0x01; // Left  (実機確認済み)
    if (byte1 & 0x80) newButtons |= 0x02; // Right (実機確認済み)
    bool changed = (newButtons != mouseButtons);
    if (dx_or_dy_nonzero(byte2, byte3) || changed || (force && newButtons != 0)) {
      int8_t dy = (byte2 & 0x80) ? -(int8_t)(byte2 & 0x7F) : (int8_t)(byte2 & 0x7F);
      int8_t dx = (byte3 & 0x80) ? -(int8_t)(byte3 & 0x7F) : (int8_t)(byte3 & 0x7F);
      toPico.write(0x80 | mouseId);
      toPico.write(newButtons);
      toPico.write((uint8_t)dx);
      toPico.write((uint8_t)dy);
      mouseButtons = newButtons;
    }
  } else {
    // 標準パッドレポート(先頭16bit: B Y Select Start Up Down Left Right | A X L R 0 0 0 0)
    if (isMouse) {
      // マウスモードから切り替わった瞬間、マウスボタンを強制解放
      if (mouseButtons != 0) {
        toPico.write(0x80 | mouseId);
        toPico.write((uint8_t)0);
        toPico.write((uint8_t)0);
        toPico.write((uint8_t)0);
        mouseButtons = 0;
      }
      isMouse = false;
    }
    uint16_t pad16 = (report >> 16) & 0xFFFF;
    for (int i = 0; i < 12; i++) {
      bool rawOn = ((pad16 >> (15 - i)) & 0x01) == 0; // アクティブLow
      // デバウンス: 生の読み値がN回連続で一致するまでは確定状態を変えない
      // (チャタリングがそのままキー連打として送られ、SELECT=右ShiftでWindowsの
      // 固定キー機能を誤爆させていたため追加)
      if (rawOn == padCandidate[i]) {
        if (padCandidateCount[i] < 255) padCandidateCount[i]++;
      } else {
        padCandidate[i] = rawOn;
        padCandidateCount[i] = 1;
      }
      bool pressed = padButtons[i];
      if (padCandidateCount[i] >= DEBOUNCE_THRESHOLD) {
        pressed = rawOn;
      }
      if (pressed != padButtons[i] || (force && pressed)) {
        sendSFCPadEvent(buttonBaseId, i, pressed);
        padButtons[i] = pressed;
      }
    }
  }
}

bool dx_or_dy_nonzero(uint8_t byte2, uint8_t byte3) {
  return (byte2 & 0x7F) != 0 || (byte3 & 0x7F) != 0;
}
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

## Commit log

2026-07-31 Initial commit: Famicom keyboard/zapper to USB HID adapter
    Nano (matrix scan + zapper read) + Pico (CircuitPython, USB HID) two-stage
    design, with firmware, wiring diagram, pinout/protocol docs, enclosure STL,
    and an assembled photo.
    [Famicom_ExPand_to_USB_Flame.stl]
2026-08-01 Add KiCad schematic and full connection list for SFC controller port expansion
    Covers the whole existing design (Famicom connector, Nano<->Pico UART link,
    status LEDs, mode switch) plus the planned SFC 1P/2P controller port wiring
    (shared CLOCK/LATCH, per-port DATA/D1 lines). Schematic is self-contained
    (embedded library symbols) and ERC-clean aside from expected
    missing-library-table warnings from being opened outside a full project.
    [connection_list.xlsx, famicom-expand-usb-adapter.kicad_sch]
2026-08-02 Move SFC_CLOCK from D4 to A5 so all SFC signals sit on A0-A5
    Keeps every new SFC controller-port wire on the analog header (A0-A5),
    which is physically contiguous on the Nano and easier to route than
    mixing in a separate digital pin. D4 is freed back up as a spare.
    [connection_list.xlsx, famicom-expand-usb-adapter.kicad_sch]
2026-08-02 Share DA15 pins 2/3 with SFC LATCH/DATA_1P (A0/A1), now physically wired
    Famicom expansion pins 2/3 carry no signal on the keyboard/Zapper side, so
    they're reused for the SFC controller ports' LATCH and 1P DATA lines -
    same "mutually exclusive use" pattern already applied to pins 4/5. Updates
    schematic, connection list, and docs to match the as-built wiring.
    [connection_list.xlsx, famicom-expand-usb-adapter.kicad_sch]
2026-08-02 Revert DA15 pin2/3 <-> A0/A1 sharing; identified as AudioOUT/IRQ
    Real-hardware investigation found DA15 pins 2/3 are actually AudioOUT and
    IRQ, not unused - sharing them with the SFC LATCH/DATA_1P lines would have
    collided with real signals. Expansion-port side physically cut; A0-A5 are
    now dedicated solely to the SFC controller ports. This also means the
    Famicom keyboard/Zapper and SFC controllers can now be used at the same
    time (keyboard vs Zapper still exclusive - single J1 socket).
    [connection_list.xlsx, famicom-expand-usb-adapter.kicad_sch]
2026-08-02 Implement SFC controller/mouse reading (Nano) and HID output (Pico)
    Nano: reads both SFC ports every scan cycle (shared CLOCK/LATCH, per-port
    DATA), auto-detects standard pad vs mouse via the mouse's fixed 0x00 first
    byte + signature, and forwards pad button edges / mouse delta+button
    packets to the Pico over UART (bumped 9600->57600bps since mouse packets
    are 4 bytes). Pico maps pad buttons to keyboard keys (remappable via
    KEYMAP_SFC1/2) and mouse reports to Mouse.move()/press()/release(), fully
    independent of the existing keyboard/Zapper mode switch so everything can
    run at once. Added a 100ms heartbeat resend for held buttons so the
    existing silence-based watchdog doesn't release them mid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
    [code.py, famicom_scanner.ino]
2026-08-02 Mark SFC standard-pad support as hardware-verified
    Button polarity, bit order (L/R correctly landing on Q/W), and CLOCK/LATCH
    timing all confirmed working on real hardware. Mouse support still needs
    verification.
2026-08-02 Add browser-based Zapper test range game
    Standalone HTML shooting gallery for exercising the Zapper end-to-end:
    trigger (left click) shoots targets with distance-based scoring, and both
    trigger and sensor lines drive live indicator lamps so the page doubles as
    a plain wiring check without starting a round. Shot history is logged to
    help spot chatter or dropped events.
2026-08-02 Rewrite Zapper test game to use real Duck Hunt scan detection
    The previous version wrongly assumed the Zapper reports a position - it
    does not, it is only a photodiode plus a trigger switch. Replaced the
    cursor-based hit test with the authentic sequence: blank the screen to
    black (which also catches a sensor stuck on ambient light, same as the
    original anti-cheat), then flash each target white one at a time and
    identify the hit by *when* the sensor fires.
    Flash windows default to 150ms rather than the hardware's one frame,
    since USB HID adds latency the original never had; because detection no
    longer depends on frame-accurate timing, this also works on LCDs.
    Also unified the frame loop on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
2026-08-04 Fix SFC mouse detection/decode and tune responsiveness (hardware-verified)
    Real-hardware debugging (raw bit capture + button press/release diffing)
    found two bugs in the original mouse handling:
    - Detection used byte0==0x00, but the wire is fully active-low so a real
    mouse's fixed sync byte reads as raw 0xFF - and a standard pad with all
    8 first-byte buttons released *also* reads 0xFF, so this could have
    misclassified an idle pad as a mouse. Switched to checking the mouse's
    fixed signature nibble instead (rawByte1 & 0x0F == 0x0E), which is
    unambiguous in both directions.
    - L/R button bits were read from the wrong position (assumed bit0/1);
    disassembly-confirmed dead right-button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
    [code.py, famicom_scanner.ino]
2026-08-04 Mark SFC mouse right-click as hardware-verified
    Replaced the failed right-button switch with a tact switch; movement and
    both clicks now confirmed working on real hardware.
2026-08-04 Split large SFC mouse moves across multiple HID reports
    At higher SFC_MOUSE_GAIN values, a single clamped move(-127..127) made
    every fast swipe saturate to the same maximum jump, discarding all speed
    information and feeling stuttery/steppy. Now sends the gained delta as a
    sequence of <=127 chunks instead of one clamped call, so fast movements
    actually travel further (and more smoothly) rather than flattening out.
2026-08-04 Interleave SFC polling into keyboard scan gaps; settle mouse gain at 12x
    Keyboard matrix scanning is dominated by settle-time delays between row
    reads, so scanSFC() now also runs once per row (10x/loop instead of 1x)
    to raise the mouse's effective sample rate without slowing keyboard
    scanning. This measurably reduced but didn't fully remove perceived
    choppiness - user attributes the remainder to the SFC mouse sensor's own
    sampling limit rather than our polling/HID path, and settled on
    SFC_MOUSE_GAIN=12 (half of the 24x tried earlier) as the preferred speed.
    [code.py, famicom_scanner.ino]
2026-08-05 Debounce SFC pad buttons to stop SELECT from triggering Sticky Keys
    SFC pad button reads had no debounce (unlike the keyboard matrix, which
    already had one). With SFC now polled ~10x per keyboard-scan loop, switch
    contact bounce on SELECT (mapped to right Shift) was arriving fast enough
    to look like Windows' 5x-Shift-tap Sticky Keys gesture. Added the same
    candidate/count debounce the keyboard matrix already uses, per pad button
    per port.
2026-08-05 Note the SFC button debounce fix in README
2026-08-05 Add runtime toggle between desktop (12x) and native (1x) SFC mouse gain
    The 12x gain exists because the real SFC mouse resolution is far coarser
    than a modern USB mouse, so raw counts feel sluggish on the desktop.
    But that correction is exactly wrong for emulators. RetroArch's emulated
    SNES Mouse expects raw SFC mouse counts, so feeding it pre-scaled deltas
    applies the correction twice and the cursor flies off - Mario Paint is
    unusable. The Pico cannot see what is running on the PC, so this has to
    be a manual switch: hold both mouse buttons for 1s to toggle, with LED
    feedback (1 lit = native, 4 lit = desktop).
    Verified on real hardware with a self-dumped Mario Paint cart.
    [code.py]
